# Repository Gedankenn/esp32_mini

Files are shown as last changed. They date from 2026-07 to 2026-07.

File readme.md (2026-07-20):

# ESP32-C3 Mini Board – Hardware Design Documentation

**Author:** Fabio Slika Stella
**Target MCU:** ESP32-C3-MINI-1-N4
**Purpose:** Compact ESP32-C3 development board with USB-C power, onboard 3.3 V regulation, boot/reset buttons, status LED, and breakout header.

---

## 1. Overview

This board is designed as a minimal, robust ESP32-C3 platform focused on:

* USB-C powered operation
* Simple, well-known LDO regulation (AMS1117-3.3)
* Correct USB-C device identification
* Stable power integrity for Wi‑Fi operation
* Clean reset/boot circuitry
* Easy access to GPIOs through a 1×11 header

The schematic is divided into the following functional blocks:

1. USB-C power input
2. 3.3 V linear regulation
3. ESP32-C3 core circuit
4. Boot and reset buttons
5. Status LED
6. GPIO breakout connector

---

## 2. USB-C Power Input

### 2.1 USB-C Receptacle (J3)

The USB-C connector is used only as a **5 V power source** and optionally for **USB data (D+/D−)**.

Key design points:

* **VBUS → 5 V net** supplies the regulator input.
* **GND and shield** are tied to board ground for EMC and ESD robustness.
* **D+ and D−** are routed directly to the ESP32-C3 USB pins, enabling native USB functionality (CDC/JTAG/DFU).

### 2.2 CC Configuration Resistors (R1, R2 – 5.1 kΩ)

Two 5.1 kΩ pull-down resistors are connected from **CC1 and CC2 to GND**.

This advertises the board as a **USB device (UFP)** and ensures that any USB-C charger or host enables VBUS. Without these resistors, many USB-C power sources would not provide 5 V.

This follows the USB-C specification for default current mode.

### 2.3 Input Decoupling Capacitor

A **10 µF bulk capacitor** is placed near VBUS to:

* Absorb hot‑plug inrush current
* Reduce cable-induced transients
* Provide local energy storage before the LDO

---

## 3. 3.3 V Regulation Stage

### 3.1 Regulator Choice – AMS1117-3.3 (U6)

The AMS1117-3.3 is a classic linear regulator chosen for:

* High availability and low cost
* Simple application circuit
* Ability to supply the peak current required by ESP32-C3 (~400 mA bursts)

Although not the most efficient, it is electrically forgiving and ideal for USB-powered boards.

### 3.2 Input and Output Capacitors (C5, C6, C1, C2)

* **Input:** 10 µF + 0.1 µF
* **Output:** 10 µF + 0.1 µF

Reasons for this combination:

* 10 µF provides bulk energy storage and stabilizes the LDO control loop.
* 0.1 µF ceramic handles high-frequency noise and fast current spikes.

This is critical for ESP32 devices, which draw fast, high di/dt current during RF transmissions.

### 3.3 Power LED (R3 + D1)

A green LED connected to 3.3 V through a 180 Ω resistor provides:

* Visual confirmation that the regulator is active
* Quick debugging aid for power faults

The resistor value balances brightness and current consumption.

---

## 4. ESP32-C3 Core Circuit

### 4.1 Module Choice – ESP32-C3-MINI-1-N4

This module integrates:

* ESP32-C3 RISC‑V MCU
* 4 MB flash
* RF matching network and antenna

Using the module instead of the bare chip:

* Simplifies RF design
* Reduces certification risk
* Minimizes layout complexity

### 4.2 Power Decoupling (C7, C8)

Placed close to the 3V3 pin:

* 10 µF for bulk decoupling
* 0.1 µF for high-frequency suppression

This ensures local current delivery and reduces ground bounce and digital noise.

### 4.3 Enable (EN) Circuit (R6 + C15)

* **R6 (10 kΩ)** pulls EN up to 3.3 V.
* **C15 (10 µF)** to GND forms a power‑on reset delay.

Purpose:

* Guarantees a clean rising edge on EN
* Prevents unstable startup
* Ensures the ESP32 only boots after 3.3 V is fully settled

This RC network increases reliability during slow USB ramps or noisy power conditions.

---

## 5. Boot and Reset Buttons

Two buttons are provided to control ESP32 startup modes.

### 5.1 Reset / Enable Button (SW2 – chip_pu)

This button pulls **EN (chip_pu)** low when pressed, forcing a hardware reset.

Supporting components:

* 10 kΩ pull‑up keeps EN high during normal operation.
* 0.1 µF capacitor filters contact bounce and short spikes.

### 5.2 Boot Button (SW1 – GPIO9)

GPIO9 is a strapping pin used by ESP32-C3 to enter download/bootloader mode.

Pressing this button while resetting the chip forces USB boot mode, enabling firmware flashing.

Again, the RC network improves noise immunity and button behavior.

---

## 6. USB Data Connection

D+ and D− from the USB-C connector are routed directly to the ESP32-C3 USB pins.

This allows:

* Native USB CDC (serial)
* USB-JTAG debugging
* DFU-style firmware loading

No external USB‑UART is required, reducing cost and component count.

---

## 7. GPIO Breakout Connector

### 7.1 1×11 Header (J1)

This header exposes:

* Multiple GPIOs
* RXD0 / TXD0
* Power and ground references

Design goals:

* Breadboard-friendly development
* External sensor and peripheral connection
* Programming and debugging access

The selection prioritizes commonly used pins while avoiding conflict with USB and boot strapping pins.

---

## 8. Power Integrity and EMC Considerations

Several design choices were made specifically for ESP32 stability:

* Multiple local decoupling capacitors
* RC delay on EN
* Short power paths from regulator to MCU
* Ground-referenced USB shield

These minimize:

* Brownouts during Wi‑Fi transmission
* Spurious resets
* USB disconnections
* EMI-related malfunctions

---

## 9. Design Philosophy Summary

This board follows a **"minimal but electrically solid"** philosophy:

* Proven components instead of experimental ones
* Conservative decoupling strategy
* USB-C implemented according to spec
* Explicit support for flashing and recovery

The result is a compact ESP32-C3 platform suitable for:

* Embedded product prototypes
* Firmware development
* USB-based tools
* IoT experiments and low-volume hardware projects

---

## 10. Revision History

### v0.1.1 (2026-07-19)

**Fixes applied:**
- **AMS1117 tab (pad 4):** Changed from GND to 3V3 (VOUT). The SOT‑223 tab is VOUT in the fixed 3.3V AMS1117.
- **C15 EN capacitor:** Changed from 1 µF 0402 to 10 µF 0603. With R6=10 kΩ this gives ~100 ms RC delay.
- **C5 voltage rating:** 6.3 V → 10 V on the 5 V rail for proper safety margin.
- **Standardized net names:** `Io0` → `IO0`, `gpio9` → `IO9`, `I01..I04` → `IO1..IO4`
- **Silkscreen** updated to match new net names.

### Recommended Next Steps (do in KiCad GUI)

1. **Add debounce capacitor C16 (0.1 µF, 0402)** from IO9 (BOOT) to GND near SW1. Route tracks on PCB.
2. **Add ESD protection** on USB D+/D−. Use USBLC6‑2 (SOT‑23‑6) or SRV05‑4 between D+/D− and GND near J3.
3. **Add USB series termination** R7, R8 = 22 Ω (0603) on D+ and D− between J3 and U1. Mark as DNP — populate only if USB signal integrity issues arise.
4. **Add 4× M3 mounting holes** (3.2 mm) at board corners: (69, 56), (99.5, 56), (69, 84.5), (99.5, 84.5).
5. **AMS1117 stability:** Output capacitors are ceramic (very low ESR). AMS1117 requires ESR ≥ 0.1 Ω. Replace C1 with a 10 µF tantalum, or add a 1 Ω resistor in series with C1.
6. **Run DRC** after all changes.

---

## 11. Possible Future Improvements

* Replace AMS1117 with a high‑efficiency buck or low‑IQ LDO
* Add ESD diodes on USB D+/D−
* Add current measurement shunt
* Expose additional GPIOs
* Add battery support and charger IC

---

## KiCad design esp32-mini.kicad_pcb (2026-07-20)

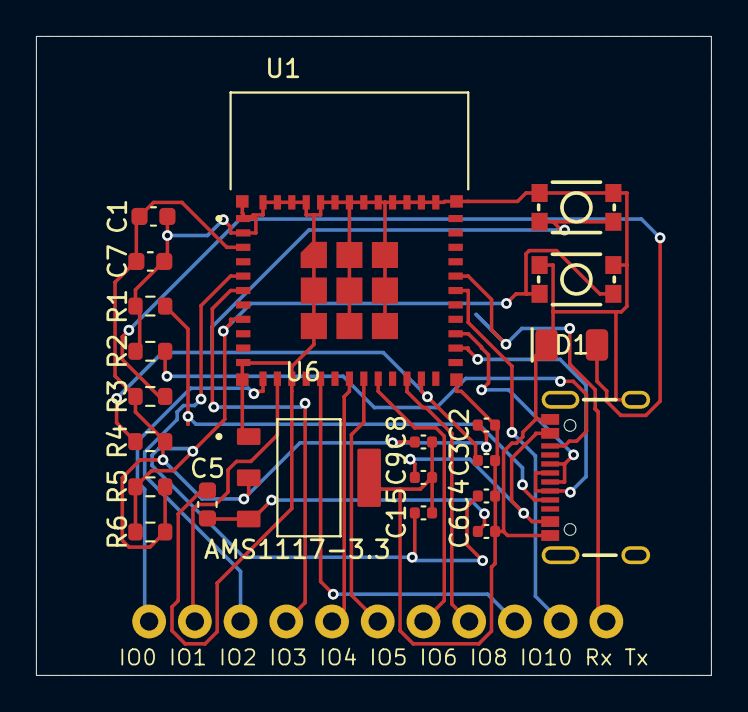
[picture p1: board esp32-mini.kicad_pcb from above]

Board: 2 copper layers, 37.5 x 35.5 mm, 23 parts (0 on the bottom side), 22 nets.

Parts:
C1, C5, C7: 10uF; C_0603_1608Metric
C2, C3, C4, C6, C8, C9: 0.1uF; C_0402_1005Metric
C15: 10uF; C_0402_1005Metric
D1: Green; LED_1206_3216Metric_Green
J1: Conn_01x11; 1x11_P2.54mm
J3: USB_C_Receptacle; USB-C_16
R1, R2: 5.1k; R_0603_1608Metric
R3: 180; R_0603_1608Metric
R4, R5, R6: 10k; R_0603_1608Metric
SW1, SW2: SMD_4.6x2.8mm_h2.5mm; Push_SMD_4.6x2.8mm_h2.5mm
U1: ESP32-C3-MINI-1-N4; XCVR_ESP32-C3-MINI-1-N4
U6: AMS1117-3.3; SOT229P700X180-4N

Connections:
3V3: C1.1, C2.1, C7.1, C8.1, R3.1, R4.2, R5.2, R6.2, U1.3 (3V3), U6.2 (VOUT), U6.4 (VOUT)
5V: C5.1, C6.1, U6.3 (VIN)
D+: J3.A6 (D+), J3.B6 (D+), U1.27 (IO19)
D-: J3.A7 (D-), J3.B7 (D-), U1.26 (IO18)
GND: C1.2, C2.2, C3.2, C4.2, C5.2, C6.2, C7.2, C8.2, C9.2, C15.2, D1.1 (K), J3.GND, J3.S (SHIELD), R1.1, R2.1, SW1.1, SW2.1, U1.1 (GND), U1.2 (GND), U1.11 (GND), U1.14 (GND), U1.36 (GND), U1.37 (GND), U1.38 (GND), U1.39 (GND), U1.40 (GND), U1.41 (GND), U1.42 (GND), U1.43 (GND), U1.44 (GND), U1.45 (GND), U1.46 (GND), U1.47 (GND), U1.48 (GND), U1.49_1 (GND), U1.49_2 (GND), U1.49_3 (GND), U1.49_4 (GND), U1.49_5 (GND), U1.49_6 (GND), U1.49_7 (GND), U1.49_8 (GND), U1.49_9 (GND), U1.50 (GND), U1.51 (GND), U1.52 (GND), U1.53 (GND), U6.1 (GND)
IO0: J1.1, U1.12 (IO0)
IO1: J1.2, U1.13 (IO1)
IO2: J1.3, U1.5 (IO2)
IO3: J1.4, U1.6 (IO3)
IO4: J1.5, U1.18 (IO4)
IO5: J1.6, U1.19 (IO5)
IO6: J1.7, U1.20 (IO6)
IO8: J1.8, U1.22 (IO8)
IO9: C3.1, R4.1, SW1.2, U1.23 (IO9)
IO10: J1.9, U1.16 (IO10)
unnamed: D1.2 (A), R3.2
unnamed: J3.A5 (CC1), R1.2
unnamed: J3.B5 (CC2), R2.2
RxD0: J1.10, U1.30 (RXD0)
TxD0: J1.11, U1.31 (TXD0)
Vusb: C9.1, J3.VBUS
chip_pu: C4.1, C15.1, R5.1, R6.1, SW2.2, U1.8 (EN)

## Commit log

2026-01-13 update schematic and pcb layout
    [esp32-mini.kicad_pcb, freerouting.dsn, temp-freerouting.dsn]
2026-07-20 minor fixes
    [esp32-mini.kicad_pcb, esp32-mini.kicad_sch]
2026-10-21 docs: note that the C5 10 V rating is only in the PCB, not the schematic
2026-10-21 chore: stop tracking KiCad backups and caches (#1)
